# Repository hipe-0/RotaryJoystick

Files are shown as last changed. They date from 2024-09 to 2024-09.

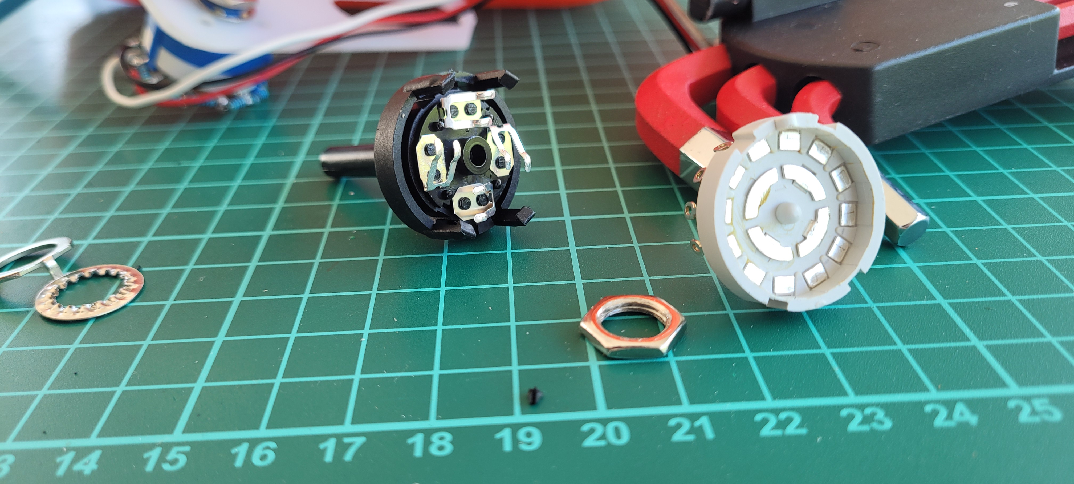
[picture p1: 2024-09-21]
20230911_161413.jpg

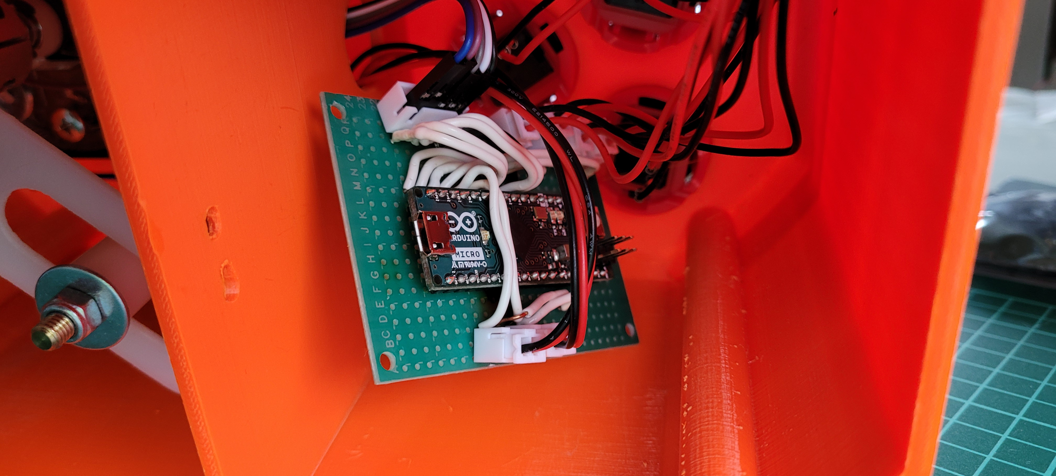
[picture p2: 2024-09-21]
20230829_080215.jpg

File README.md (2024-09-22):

# RotaryJoystick
This arduino-based DIY game controler has a special twisting joystick with 12 increments. This is especially useful for playing a handful of retro-games of the 90's. I personaly remember.
- XYBOTS  https://en.wikipedia.org/wiki/Xybots
- Ikari warrior https://en.wikipedia.org/wiki/Ikari_Warriors
- time soldiers https://en.wikipedia.org/wiki/Time_Soldiers

https://github.com/user-attachments/assets/40a15bb0-9314-4c02-8181-8543abbdb70c

3D models to be found on Thingiverse here
https://www.thingiverse.com/thing:6773750



Video demo here : [xybots_demo_using_rotary_joystick.mp4](https://github.com/hipe-0/RotaryJoystick/blob/main/xybots_demo_using_rotary_joystick.mp4)

Code : in this repository

Shematics : 
2024-09-22 Rotary joystick electric diagram v1 01_bb
2024-09-22 Rotary joystick electric diagram v1 01_schéma

New, untested yet, you can try this prototype PCB (Fritzing source file in repository):
2024-09-22 Rotary joystick electric diagram v1 01_circuit imprimé

# Bill of materials

- 1x Arduino micro
- 1x joystick kit similar to https://www.aliexpress.com/item/1005006065513751.html
- 1x rotary kit similar to[ Ikari 12-Way Rotary Upgrade Kit For Servostik Ball Top & JLW-TM-8 ](https://www.ultimarc.com/arcade-controls/joystick-accessories/ikari-12-way-rotary-upgrade-for-servostik-j-stik/)
- 2x 24mm arcade button
- 4x 30mm arcade button
- 1x 2m cable Usb A to usb micro
- 11x resistor 1000K
- 1x resistor 100 Ohm
- 1 capacitor 2.2uF
- prototyping board
- some cables
- soldering

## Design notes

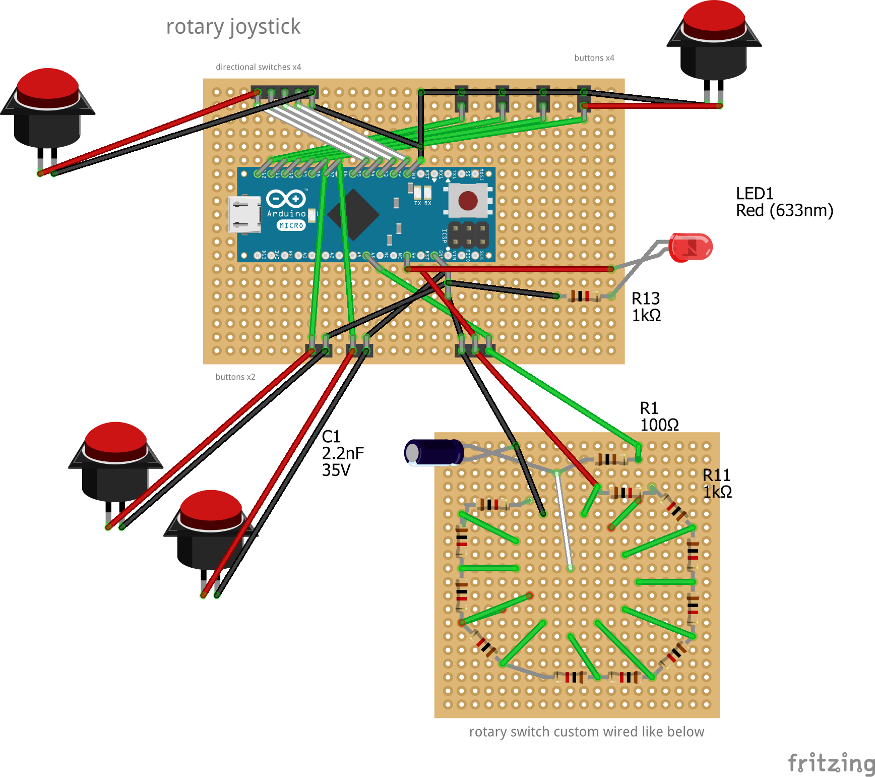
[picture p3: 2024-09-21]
2024-09-21 Rotary joystick electric diagram_bb.png

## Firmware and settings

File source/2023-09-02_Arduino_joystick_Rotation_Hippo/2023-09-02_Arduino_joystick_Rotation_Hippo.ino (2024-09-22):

// Simple gamepad example that demonstraits how to read five Arduino
// digital pins and map them to the Arduino Joystick library.
//
// The digital pins 2 - 6 are grounded when they are pressed.
// Pin 2 = UP
// Pin 3 = RIGHT
// Pin 4 = DOWN
// Pin 5 = LEFT
// Pin 6 = FIRE

// pin A5 = analog input

//
// NOTE: This sketch file is for use with Arduino Leonardo and
//       Arduino Micro only.
//

//--------------------------------------------------------------------

#include <Joystick.h>

const int ROTATION_PIN = 5;
const int ROTATION_BUTTON_LEFT=6;
const int ROTATION_BUTTON_RIGHT=7;

Joystick_ Joystick(JOYSTICK_DEFAULT_REPORT_ID,JOYSTICK_TYPE_GAMEPAD,
  8, 0,                  // Button Count, Hat Switch Count
  true, true, true,      // X, Y and Z Axis
  false, false, false,   // No Rx, Ry, or Rz
  false, false,          // No rudder or throttle
  false, false, false);  // No accelerator, brake, or steering


// Last state of the buttons
int lastdirectionState[4] = {0,0,0,0};
int lastButtonState[6] = {0,0,0,0,0,0};
int lastRotationState;

const int TIMER_FOR_ROT_BUTTON_RESET = 10;
const int ANALOG_ROTATION_THRESHOLD = 1;
int resetCounter;

void setup() {

  // Initialize Button Pins
  pinMode(7, INPUT_PULLUP);
  pinMode(8, INPUT_PULLUP);
  pinMode(9, INPUT_PULLUP);
  pinMode(10, INPUT_PULLUP);
  pinMode(11, INPUT_PULLUP);
  pinMode(12, INPUT_PULLUP);

  // Initialize Directional Pins
  pinMode(3, INPUT_PULLUP);
  pinMode(4, INPUT_PULLUP);
  pinMode(5, INPUT_PULLUP);
  pinMode(6, INPUT_PULLUP);

  // Initialize Joystick Library
  Joystick.begin();
  Joystick.setXAxisRange(-1, 1);
  Joystick.setYAxisRange(-1, 1);
  Joystick.setZAxisRange(0, 11);

  lastRotationState = analogRead(ROTATION_PIN) * 12 / 1024;
  resetCounter = 0;
}


// Constant that maps the phyical pin to the joystick button.
const int pinToButtonMap = 7;
const int pinToDirectionMap = 3;

void loop() {
  buttonCommands();
  directionalCommands();
  rotationalCommands();
  delay(10);
}

void buttonCommands()
{
  // Read pin values for buttons
  for (int index = 0; index < 6; index++)
  {
    int currentButtonState = !digitalRead(index + pinToButtonMap);
    if (currentButtonState != lastButtonState[index])
    {
      Joystick.setButton(index, currentButtonState);
      lastButtonState[index] = currentButtonState;
    }
  }
}

void directionalCommands()
{
  // Read pin values for direction
  for (int index = 0; index < 4; index++)
  {
    int currentButtonState = !digitalRead(index + pinToDirectionMap);
    if (currentButtonState != lastdirectionState[index])
    {
      switch (index) {
        case 0: // UP
          if (currentButtonState == 1) {
            Joystick.setYAxis(-1);
          } else {
            Joystick.setYAxis(0);
          }
          break;
        case 1: // RIGHT
          if (currentButtonState == 1) {
            Joystick.setXAxis(1);
          } else {
            Joystick.setXAxis(0);
          }
          break;
        case 2: // DOWN
          if (currentButtonState == 1) {
            Joystick.setYAxis(1);
          } else {
            Joystick.setYAxis(0);
          }
          break;
        case 3: // LEFT
          if (currentButtonState == 1) {
            Joystick.setXAxis(-1);
          } else {
            Joystick.setXAxis(0);
          }
          break;
      }
      lastdirectionState[index] = currentButtonState;
    }
  }
}



void rotationalCommands()
{
  int rotationValue, analogValue;
  analogValue = analogRead(ROTATION_PIN);
  rotationValue = analogValue * 12 / 1024;  // read the input pin
  int differenceWithPrevious;
  differenceWithPrevious = rotationValue - lastRotationState;
  if (differenceWithPrevious >= 11) differenceWithPrevious-= 12;
  if (differenceWithPrevious <= -11) differenceWithPrevious+= 12;
  
  lastRotationState = rotationValue;

  Joystick.setZAxis(rotationValue);
  
  Serial.print(" input=");
  Serial.println(analogValue);
  

  if ( differenceWithPrevious <= -ANALOG_ROTATION_THRESHOLD) 
  {
     Joystick.setButton(ROTATION_BUTTON_LEFT, true);
     resetCounter = TIMER_FOR_ROT_BUTTON_RESET;
     Serial.println(" <LEFT ROT> ");
  Serial.print("                    difference");
  Serial.println(differenceWithPrevious);

  }

  if ( differenceWithPrevious >= ANALOG_ROTATION_THRESHOLD) 
  {
     Joystick.setButton(ROTATION_BUTTON_RIGHT, true);
     resetCounter = TIMER_FOR_ROT_BUTTON_RESET;
     Serial.println(" <RIGHT ROT> ");
  Serial.print("                    difference");
  Serial.println(differenceWithPrevious);

  }
  

  if(resetCounter > 0) {
    //Serial.println(" reset=");
    //Serial.println(resetCounter);

    resetCounter--;
    if(resetCounter == 0) {
      Serial.println(" reset ");

      Joystick.setButton(ROTATION_BUTTON_RIGHT, false);
      Joystick.setButton(ROTATION_BUTTON_LEFT, false);
    }
  }

}

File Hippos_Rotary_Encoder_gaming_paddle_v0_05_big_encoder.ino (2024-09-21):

/* Rotary encoder game paddle
by Hippolyte Mounier
*/
#include <ezButton.h>
#include "Mouse.h"

#define CLK_PIN 3
#define CLK_PIN2 2
#define DT_PIN 4
#define SW_PIN 7


#define SPINNER_DEBOUNCE_TIME 1

volatile int           counter = 0;
volatile unsigned long last_time;  // for debouncing
volatile bool          lastWasFall;
int                    prev_counter;

ezButton ezbutton(SW_PIN);  // create ezButton object that attach to pin 4

void setup() {
  Serial.begin(9600);
  Mouse.begin();

  // configure encoder pins as inputs
  pinMode(CLK_PIN, INPUT);
  pinMode(CLK_PIN2, INPUT);
  pinMode(DT_PIN, INPUT);
  pinMode(A0, INPUT);

  ezbutton.setDebounceTime(50);  // set debounce time to 50 milliseconds

  // use interrupt for CLK pin is enough
  // call ISR_encoderChange() when CLK pin changes from LOW to HIGH
  attachInterrupt(digitalPinToInterrupt(CLK_PIN), ISR_encoderRise, RISING);
  attachInterrupt(digitalPinToInterrupt(CLK_PIN2), ISR_encoderFall, FALLING);
}

bool lastState;

void loop() 
{
  int diff;
  int sampledCounter;
  sampledCounter = counter;

  ezbutton.loop();  // MUST call the loop() function first

  if (prev_counter != sampledCounter) 
  {
    //DEBUGVAL("sampledCounter: ", sampledCounter)

    diff = (sampledCounter - prev_counter)*20;
    if(diff > 127) diff = 127;
    if(diff < -127) diff = -127;

    Mouse.move(diff, 0, 0);
    Serial.print("mouse move: ") ; Serial.println(diff);
  }

  bool b = !ezbutton.getState();

  if (b != lastState)
  {
    if (b)
    {
      Mouse.press(MOUSE_LEFT);
      Serial.println("button pressed");
    }
    else
    {
      Mouse.release(MOUSE_LEFT);
      Serial.println("button released");
    }
  }

  lastState = b;
  prev_counter = sampledCounter;

  delay(20);
}

void ISR_encoderRise() 
{
  if (!lastWasFall) return;

  int delta = millis() - last_time;
  if (delta < SPINNER_DEBOUNCE_TIME)
    return;
  last_time = millis();

  bool b = digitalRead(DT_PIN) == HIGH;
  if (b)     counter--;
  else       counter++;

  //DEBUGVAL2("rise dt", digitalRead(DT_PIN), "delta", delta)

  lastWasFall = false;
}


void ISR_encoderFall() 
{
  if (lastWasFall) return;

  int delta = millis() - last_time;
  if (delta < SPINNER_DEBOUNCE_TIME)
    return;
  last_time = millis();


  bool b = digitalRead(DT_PIN) == HIGH;
  if (b)     counter++;
  else       counter--;


  //DEBUGVAL2("    fall dt", digitalRead(DT_PIN), "delta", delta)

  lastWasFall = true;
}
